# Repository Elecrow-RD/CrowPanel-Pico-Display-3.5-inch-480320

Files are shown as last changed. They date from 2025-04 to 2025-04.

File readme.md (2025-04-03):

### 1, Product picture

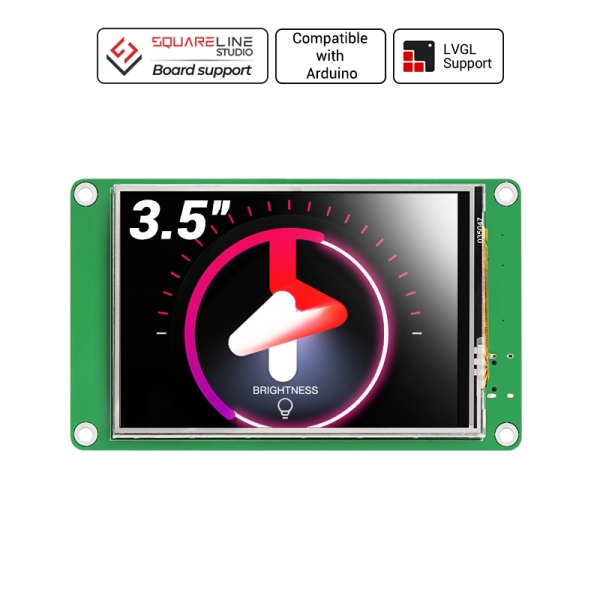
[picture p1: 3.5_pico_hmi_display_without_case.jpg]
3.5_pico_hmi_display_without_case


### 2, Product version number

| | Hardware | Software | Remark |
| ---- | --- | --- | --- |
| 1 | V1.0 | V1.0 | latest |

### 3, product information

- Main Chip: RP2040
- Processor: Dual-core 32-bit ARM Cortex-M0+ @ 133MHz
- Memory: 264kB on-chip SRAM (supports up to 16MB of off-chip flash memory)
- Screen Size: 3.5 inch
- Resolution: 480*320
- Signal Interface: SPI
- Touch Type: Resistive Touch
- Panel Type: TFT LCD
- Power Input: 5V-2A
- Active Area: 53.64*71.52mm(W * H)
- Dimensions: 62.5 * 104.5 * 13.5mm(W * H * D)

### 4, Use the driver module

| Name | dependency library |
| ---- | --- |
| LVGL | lvgl/lvgl@8.3.3 |

### 5,Quick Start

##### Arduino IDE starts

1.Download the library files used by this product to the 'libraries' folder.

C:\Users\Documents\Arduino\libraries\



2.Open the Arduino IDE

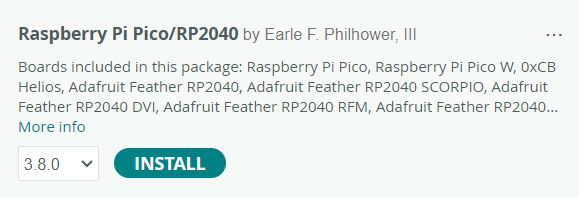
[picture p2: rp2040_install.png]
rp2040_install


3.Open the code configuration environment and burn it

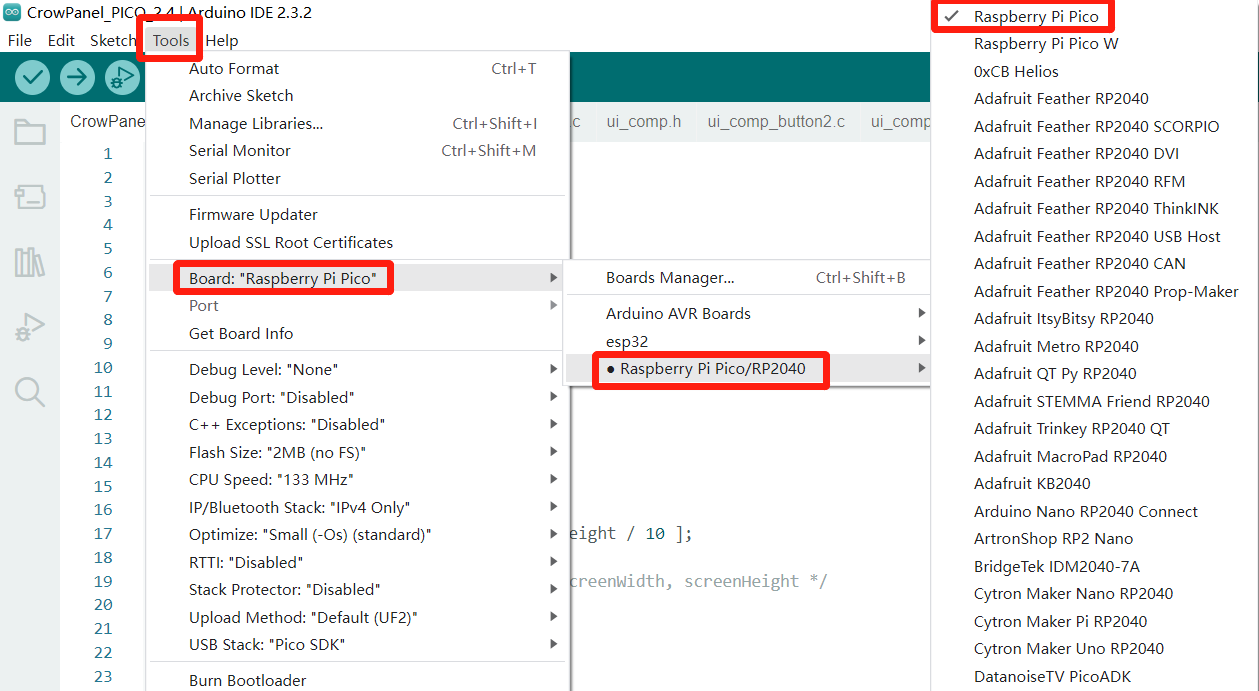
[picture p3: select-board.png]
select-board


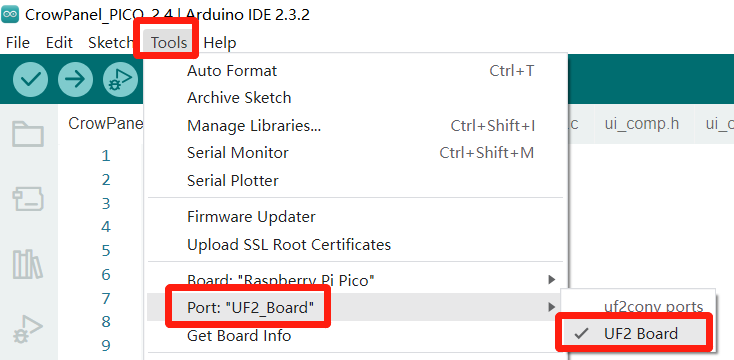
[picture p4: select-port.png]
select-port


### 6,Folder structure.

|--Dimensional Drawing: Contains the dimensional drawing file (.dwg) of the hardware.

|--Datasheet: Includes datasheets for components used in the project, providing detailed specifications, electrical characteristics, and pin configurations.

|--Eagle_SCH&PCB: Contains **Eagle CAD** schematic (`.sch`) and PCB layout (`.brd`) files. These are used for circuit design and PCB manufacturing.

|--example: Provides example code and projects to demonstrate how to use the hardware and libraries. These examples help users get started quickly.

|--factory_firmware: Stores pre-compiled factory firmware that can be directly flashed onto the device. This ensures the device runs the default functionality.

|--factory_sourcecode: Contains the source code for the factory firmware, allowing users to modify and rebuild the firmware as needed.

### 7,Pin definition

#define I2C0_SDA 20

#define I2C0_SCL 21

#SD

const int _MISO = 12;  // AKA SPI RX

const int _MOSI = 11;  // AKA SPI TX

const int _CS = 22;

const int _SCK = 10;

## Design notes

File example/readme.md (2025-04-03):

**Arduino**: This folder contains sample programs for the Arduino platform, which is known for its ease of use and versatility in creating interactive electronic projects.

Link to the corresponding course wiki:https://www.elecrow.com/wiki/CrowPanel_Pico_HMI_3.5-inch_Arduino_Tutorial.html

Video Tutorial Links：https://www.youtube.com/watch?v=5lLdKOjR-Lo&list=PLwh4PlcPx2GdvAtPGuAf1ocWj1UyPWw3W

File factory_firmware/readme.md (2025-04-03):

### pico firmware burning method

##### Press the boot button, plug the pico screen into the computer USB, pop up the disk drive letter



##### Just copy the firmware.uf2 file to the disk drive above

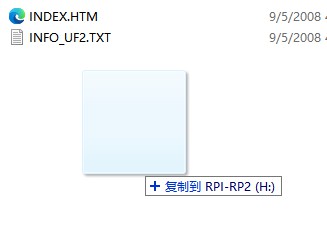
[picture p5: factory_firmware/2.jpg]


##### Demonstration effect

#####

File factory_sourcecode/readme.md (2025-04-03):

- ### Functions Overview

  ### `clearBufferArray()`
  - **Description**: Clears the buffer array by setting all indices to `NULL`.
  - **Parameters**: None
  - **Returns**: None

  ### `my_disp_flush`
  - **Description**: Handles display flushing for LVGL (LittlevGL) graphics library.
  - **Parameters**: 
    - `lv_disp_drv_t *disp_drv`: Pointer to the display driver.
    - `const lv_area_t *area`: Pointer to the area to flush.
    - `lv_color_t *color_p`: Pointer to the color data.
  - **Returns**: None

  ### `my_touchpad_read`
  - **Description**: Reads touchpad input and updates LVGL input device data.
  - **Parameters**: 
    - `lv_indev_drv_t * indev_driver`: Pointer to the input device driver.
    - `lv_indev_data_t * data`: Pointer to the input device data.
  - **Returns**: None

  #### `callback1`
  - **Description**: Callback function for updating UI elements based on certain conditions.
  - **Parameters**: None
  - **Returns**: None

  #### `setup`
  - **Description**: Initializes the system, including serial communication, display, and LVGL.
  - **Parameters**: None
  - **Returns**: None

  #### `loop`
  - **Description**: Main loop of the program handling various tasks and user inputs.
  - **Parameters**: None
  - **Returns**: None

  #### `Ce_shi`
  - **Description**: Clears the screen and handles different test cases based on serial input.
  - **Parameters**: None
  - **Returns**: None

  ### `SD_test`
  - **Description**: Tests and initializes the SD card.
  - **Parameters**: None
  - **Returns**: None

  ### `printDirectory`
  - **Description**: Prints the contents of a directory to the serial output.
  - **Parameters**: 
    - `File dir`: Directory to print.
    - `int numTabs`: Number of tabs for formatting.
  - **Returns**: None

  #### `label_xy`
  - **Description**: Creates and configures touch labels on the screen.
  - **Parameters**: None
  - **Returns**: None

  #### `lv_example_bar`
  - **Description**: Creates and configures a bar widget for the UI.
  - **Parameters**: None
  - **Returns**: None

  #### `Home_Page_Create`
  - **Description**: Sets up the home page with a black background.
  - **Parameters**: None
  - **Returns**: None

  #### `touch_calibrate`
  - **Description**: Calibrates the touch screen and sends calibration data to the serial port.
  - **Parameters**: None
  - **Returns**: None

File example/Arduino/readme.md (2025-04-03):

# Library Descriptions

## Adafruit_BusIO
Adafruit_BusIO is a library that provides a common interface for communicating with I2C, SPI, and other bus protocols on microcontrollers like the Raspberry Pi Pico.

## Adafruit_GFX_Library
The Adafruit GFX Library is a graphics library that simplifies drawing shapes, text, and images on displays connected to microcontrollers.

## Adafruit_seesaw_Library
The Adafruit seesaw Library allows you to communicate with Adafruit's seesaw devices, which can add additional functionality such as capacitive touch sensing or analog-to-digital conversion to your projects.

## Adafruit_ST7735_and_ST7789_Library
This library supports the ST7735 and ST7789 display controllers, commonly used in small TFT displays.

## DHT20
The DHT20 library is designed for interfacing with the DHT20 temperature and humidity sensor.

## GFX_Library_for_Arduino
This is likely another graphics library specifically tailored for Arduino-based projects.

## GuSlice
GuSlice might be a library for handling graphical user interface elements, particularly slices or segments of a display.

## lvg1
lvg1 could refer to a version or variant of the LittlevGL (LVGL) library, which is a popular open-source GUI library.

## TFT_eSPI
TFT_eSPI is a library for driving TFT displays using the SPI protocol, often used with ESP8266 and ESP32 microcontrollers.

## Ticker
Ticker is typically a library for creating software timers or scheduling tasks at regular intervals.

## UI
UI generally refers to a set of functions or classes related to the user interface, possibly custom code or part of a larger framework.

## Wire
Wire is a library for I2C communication, allowing microcontrollers to talk to each other and to various sensors and modules over the I2C bus.

## XPT2046_Touchscreen
This library interfaces with the XPT2046 touchscreen controller, enabling touch input on compatible displays.

## lv_conf.h
lv_conf.h is a configuration file for the LVGL library where you can define various settings and options to tailor the library's behavior to your specific needs.

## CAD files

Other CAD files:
Dimension_figure/3.5_inch_dimension_figure/3.5inch.dwg

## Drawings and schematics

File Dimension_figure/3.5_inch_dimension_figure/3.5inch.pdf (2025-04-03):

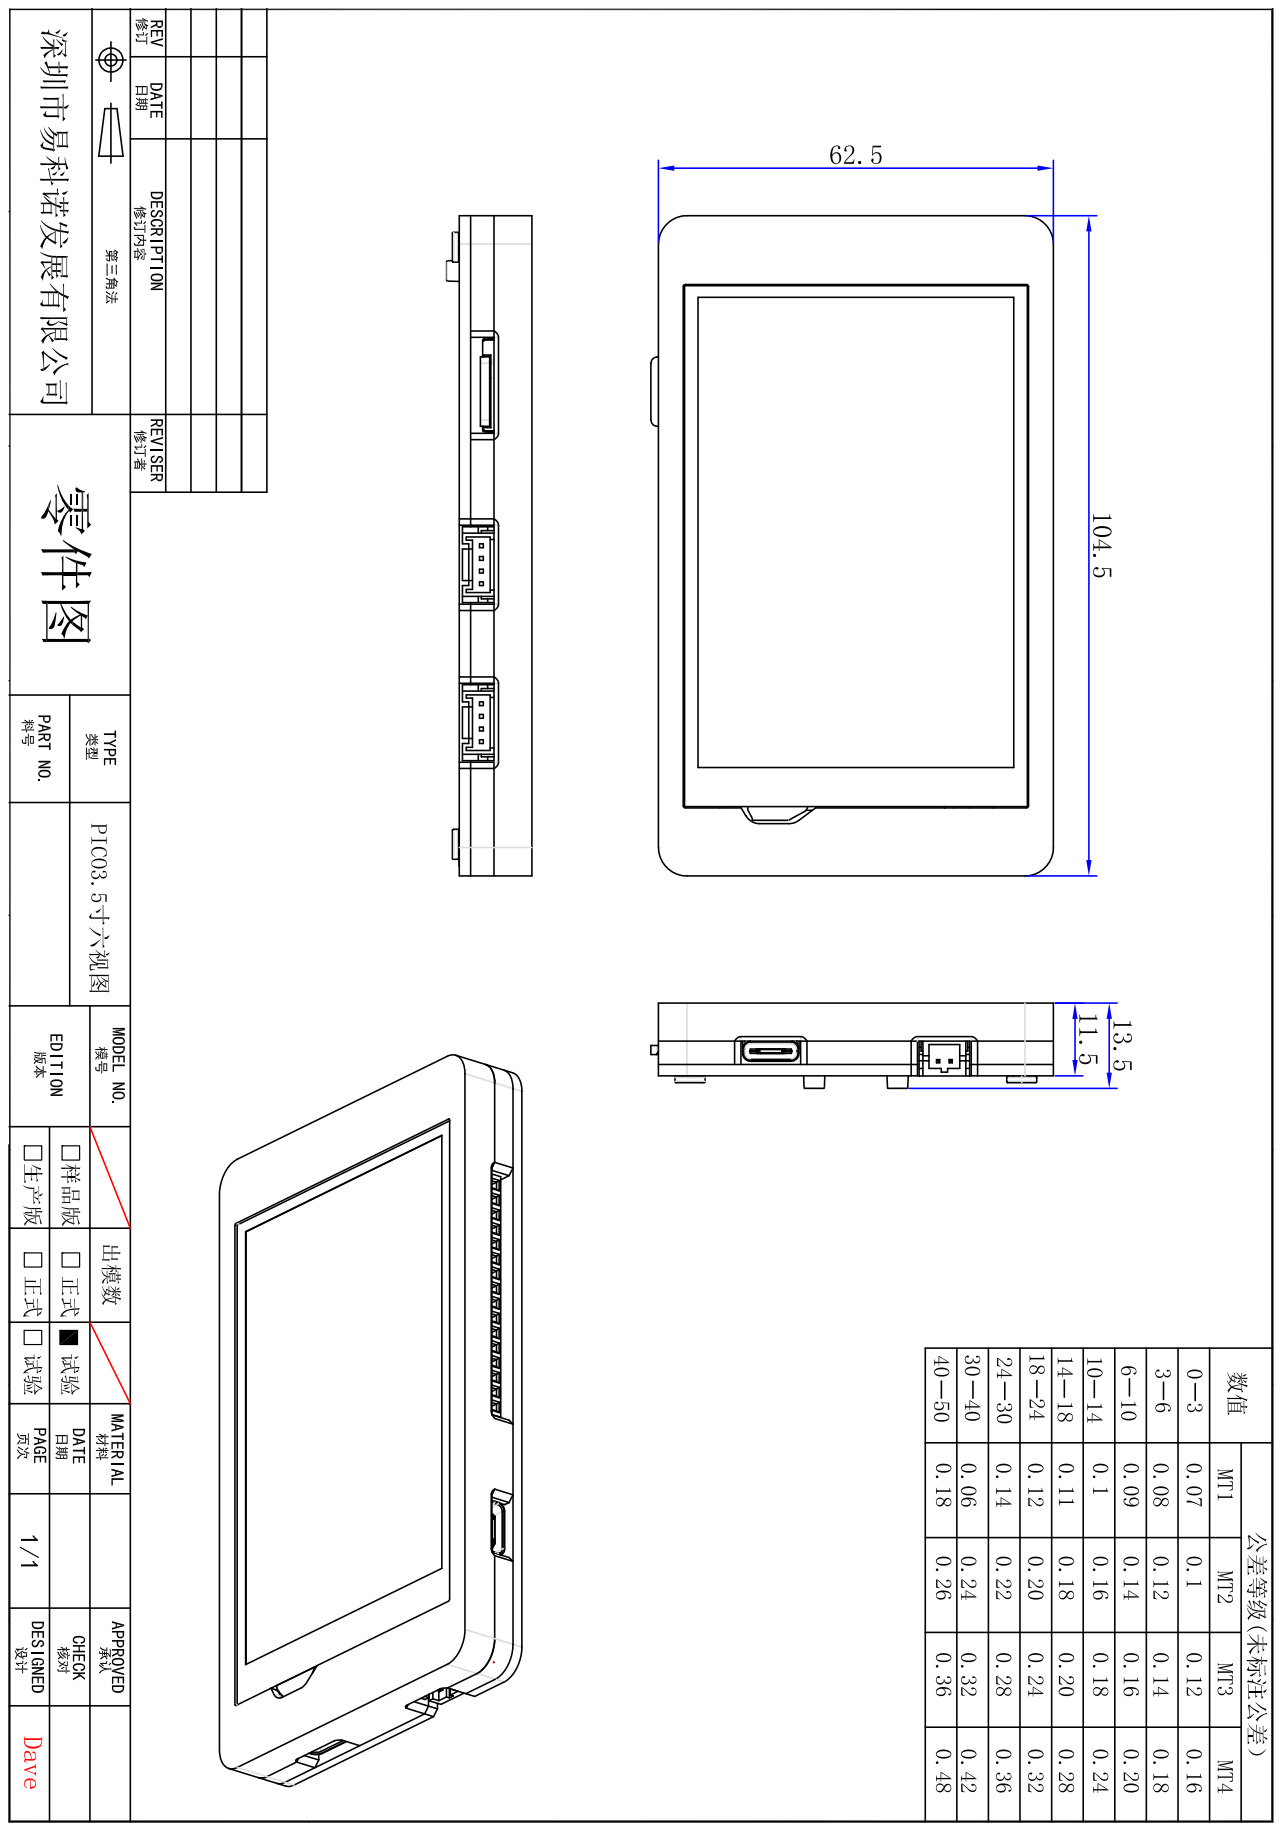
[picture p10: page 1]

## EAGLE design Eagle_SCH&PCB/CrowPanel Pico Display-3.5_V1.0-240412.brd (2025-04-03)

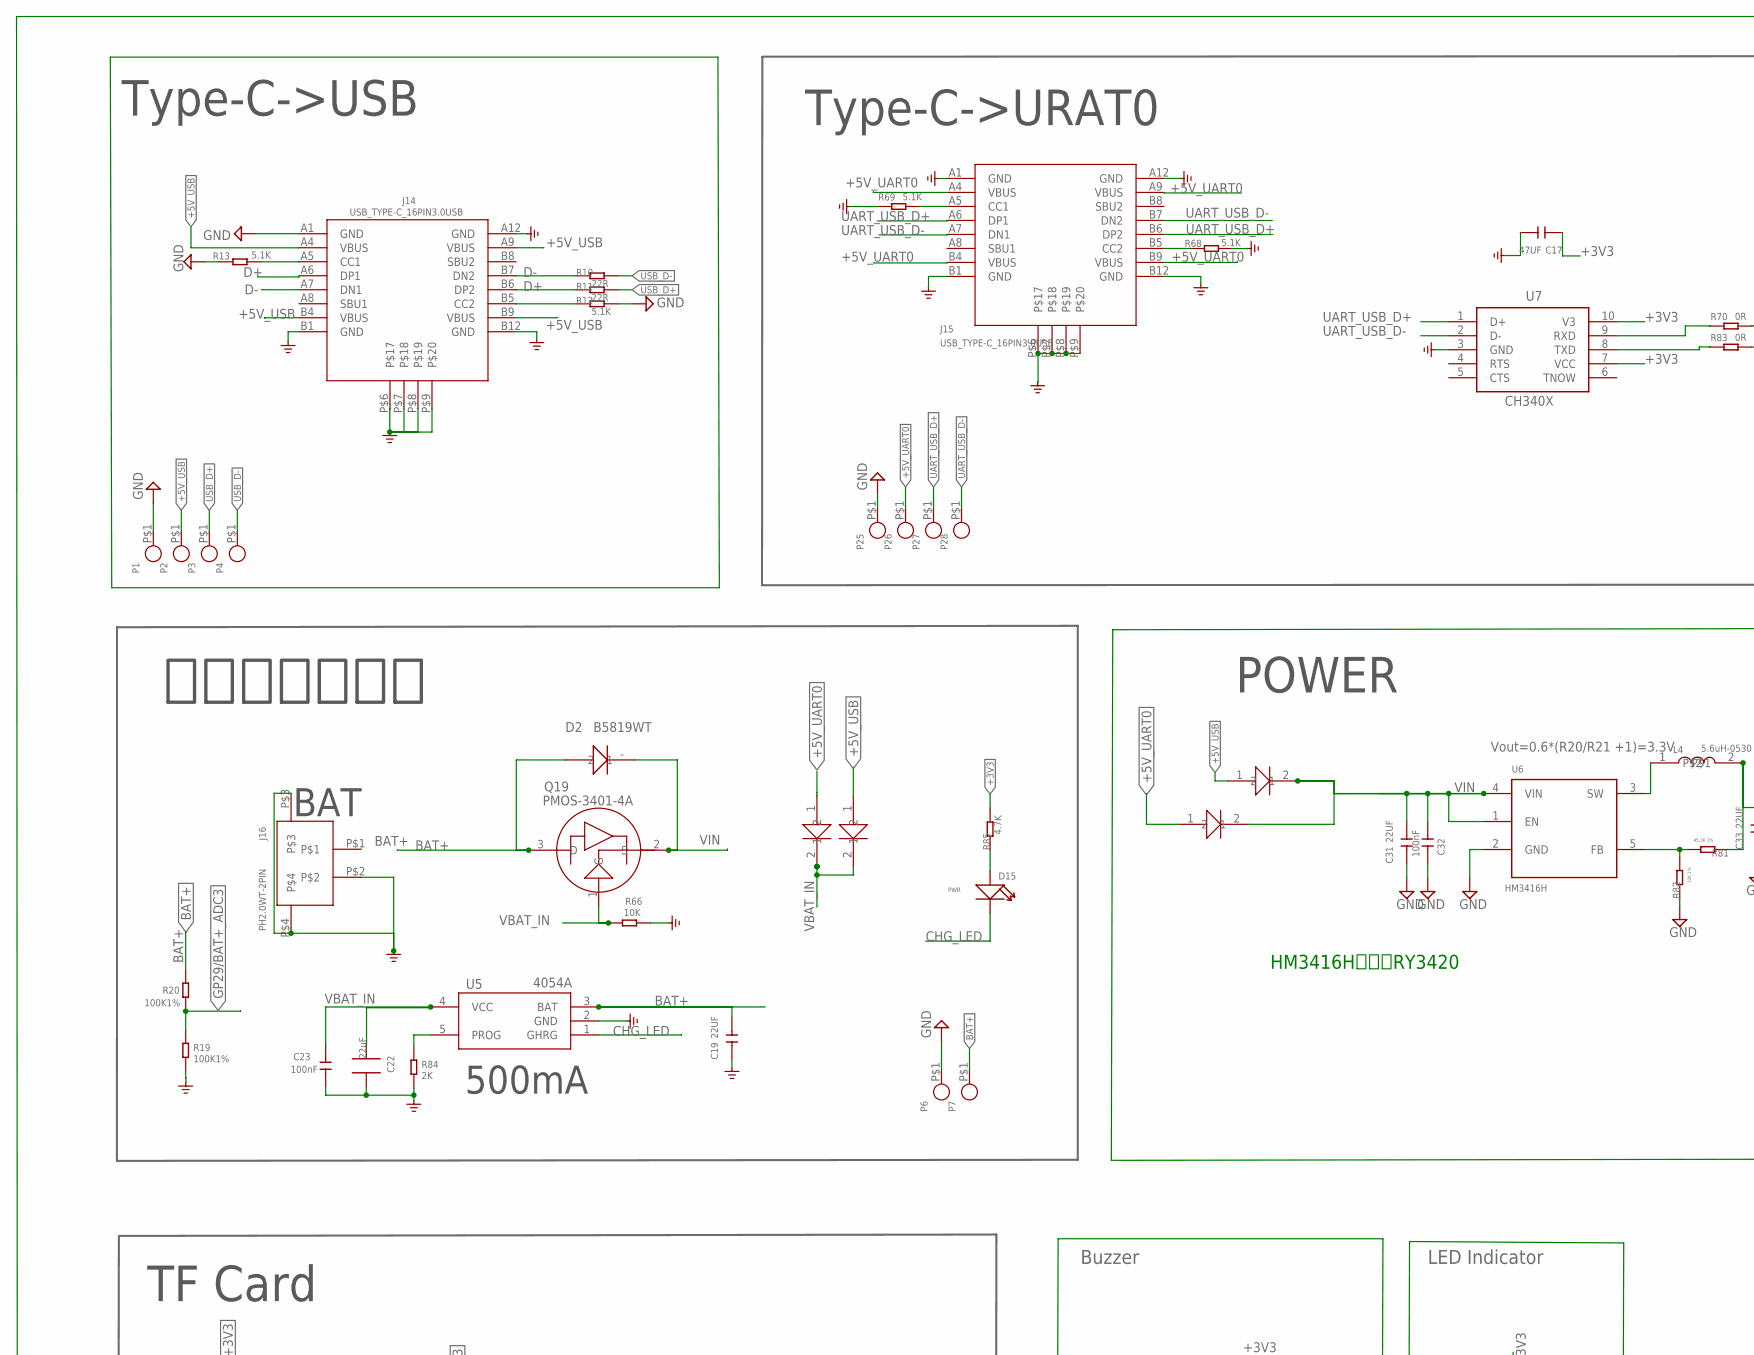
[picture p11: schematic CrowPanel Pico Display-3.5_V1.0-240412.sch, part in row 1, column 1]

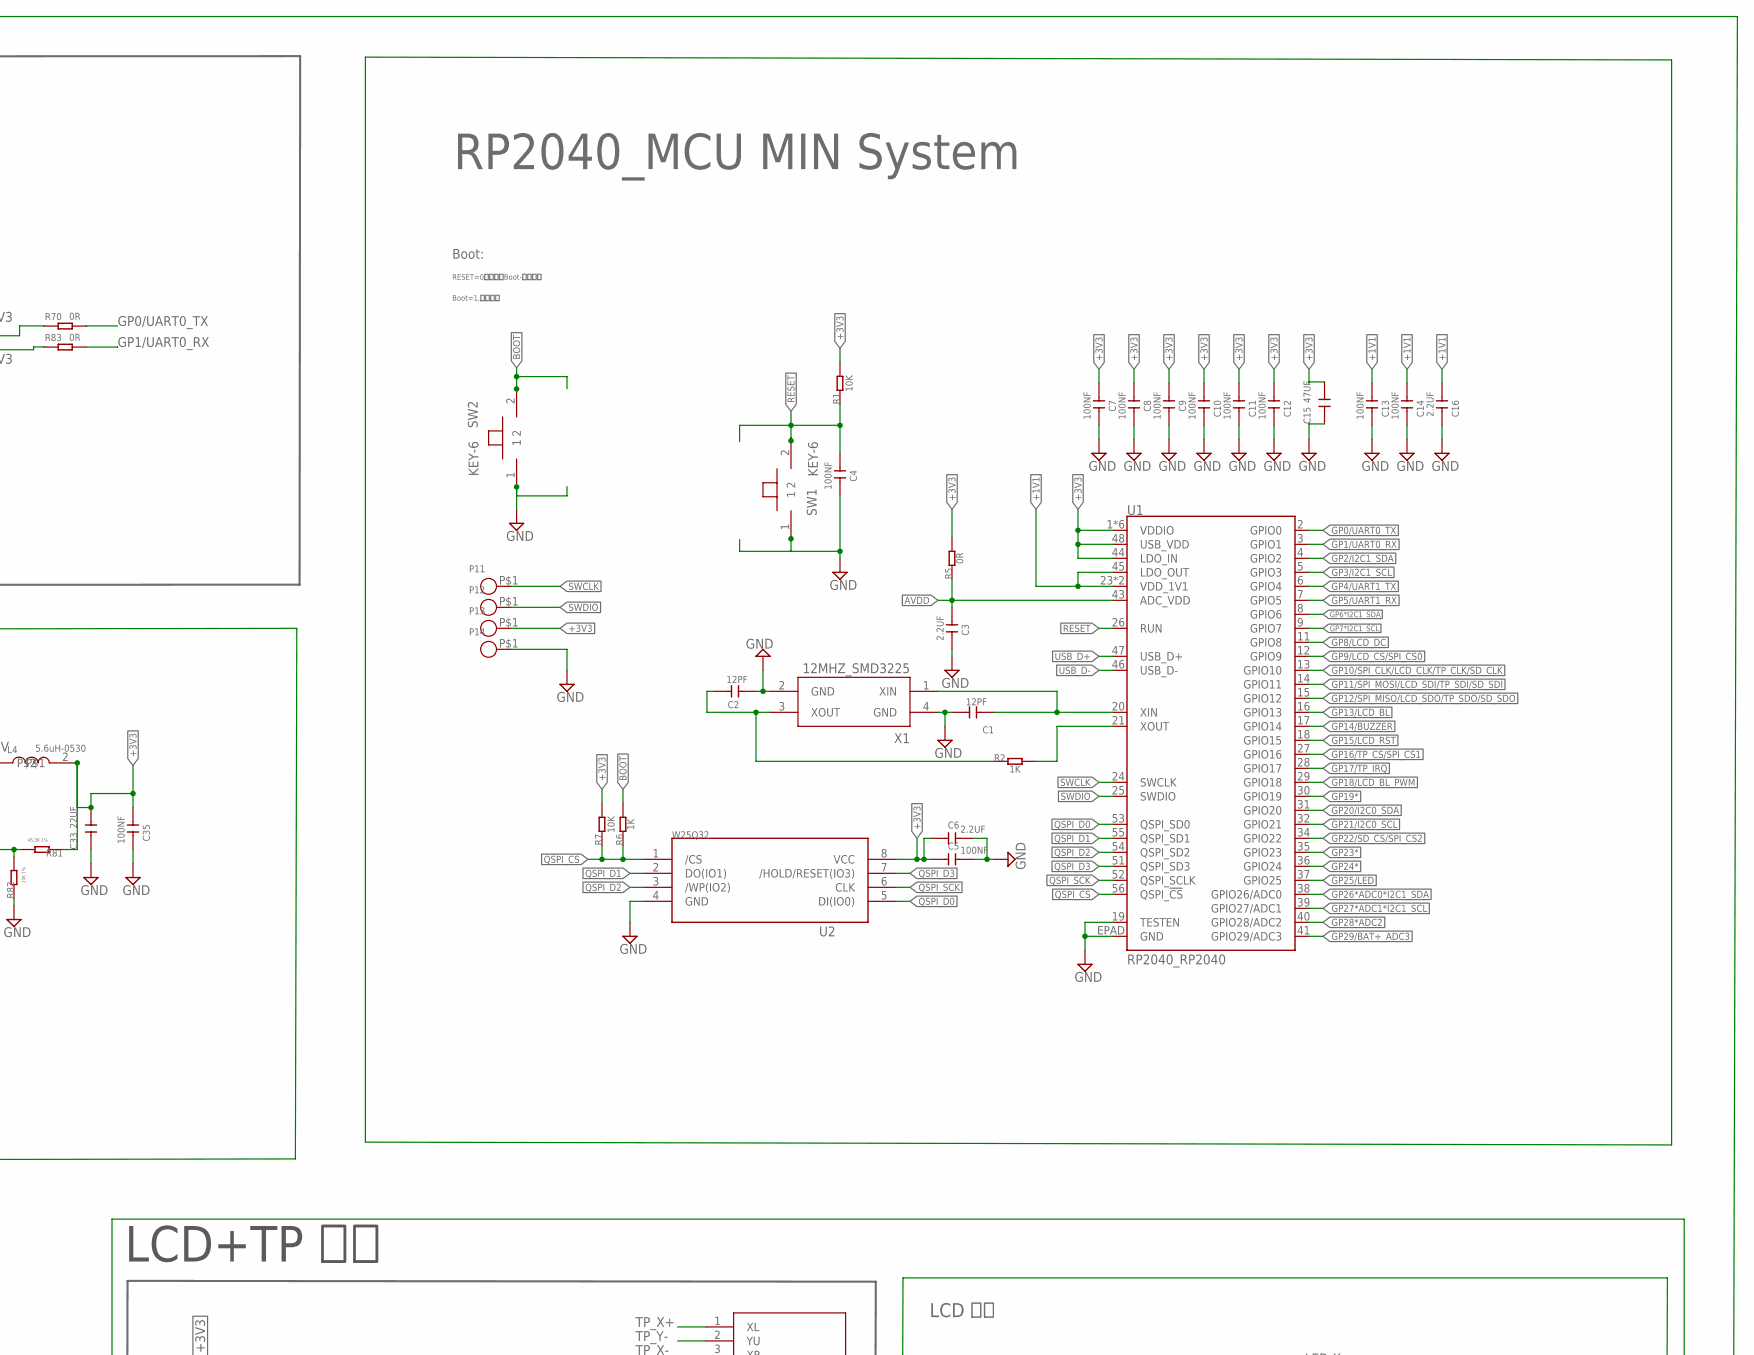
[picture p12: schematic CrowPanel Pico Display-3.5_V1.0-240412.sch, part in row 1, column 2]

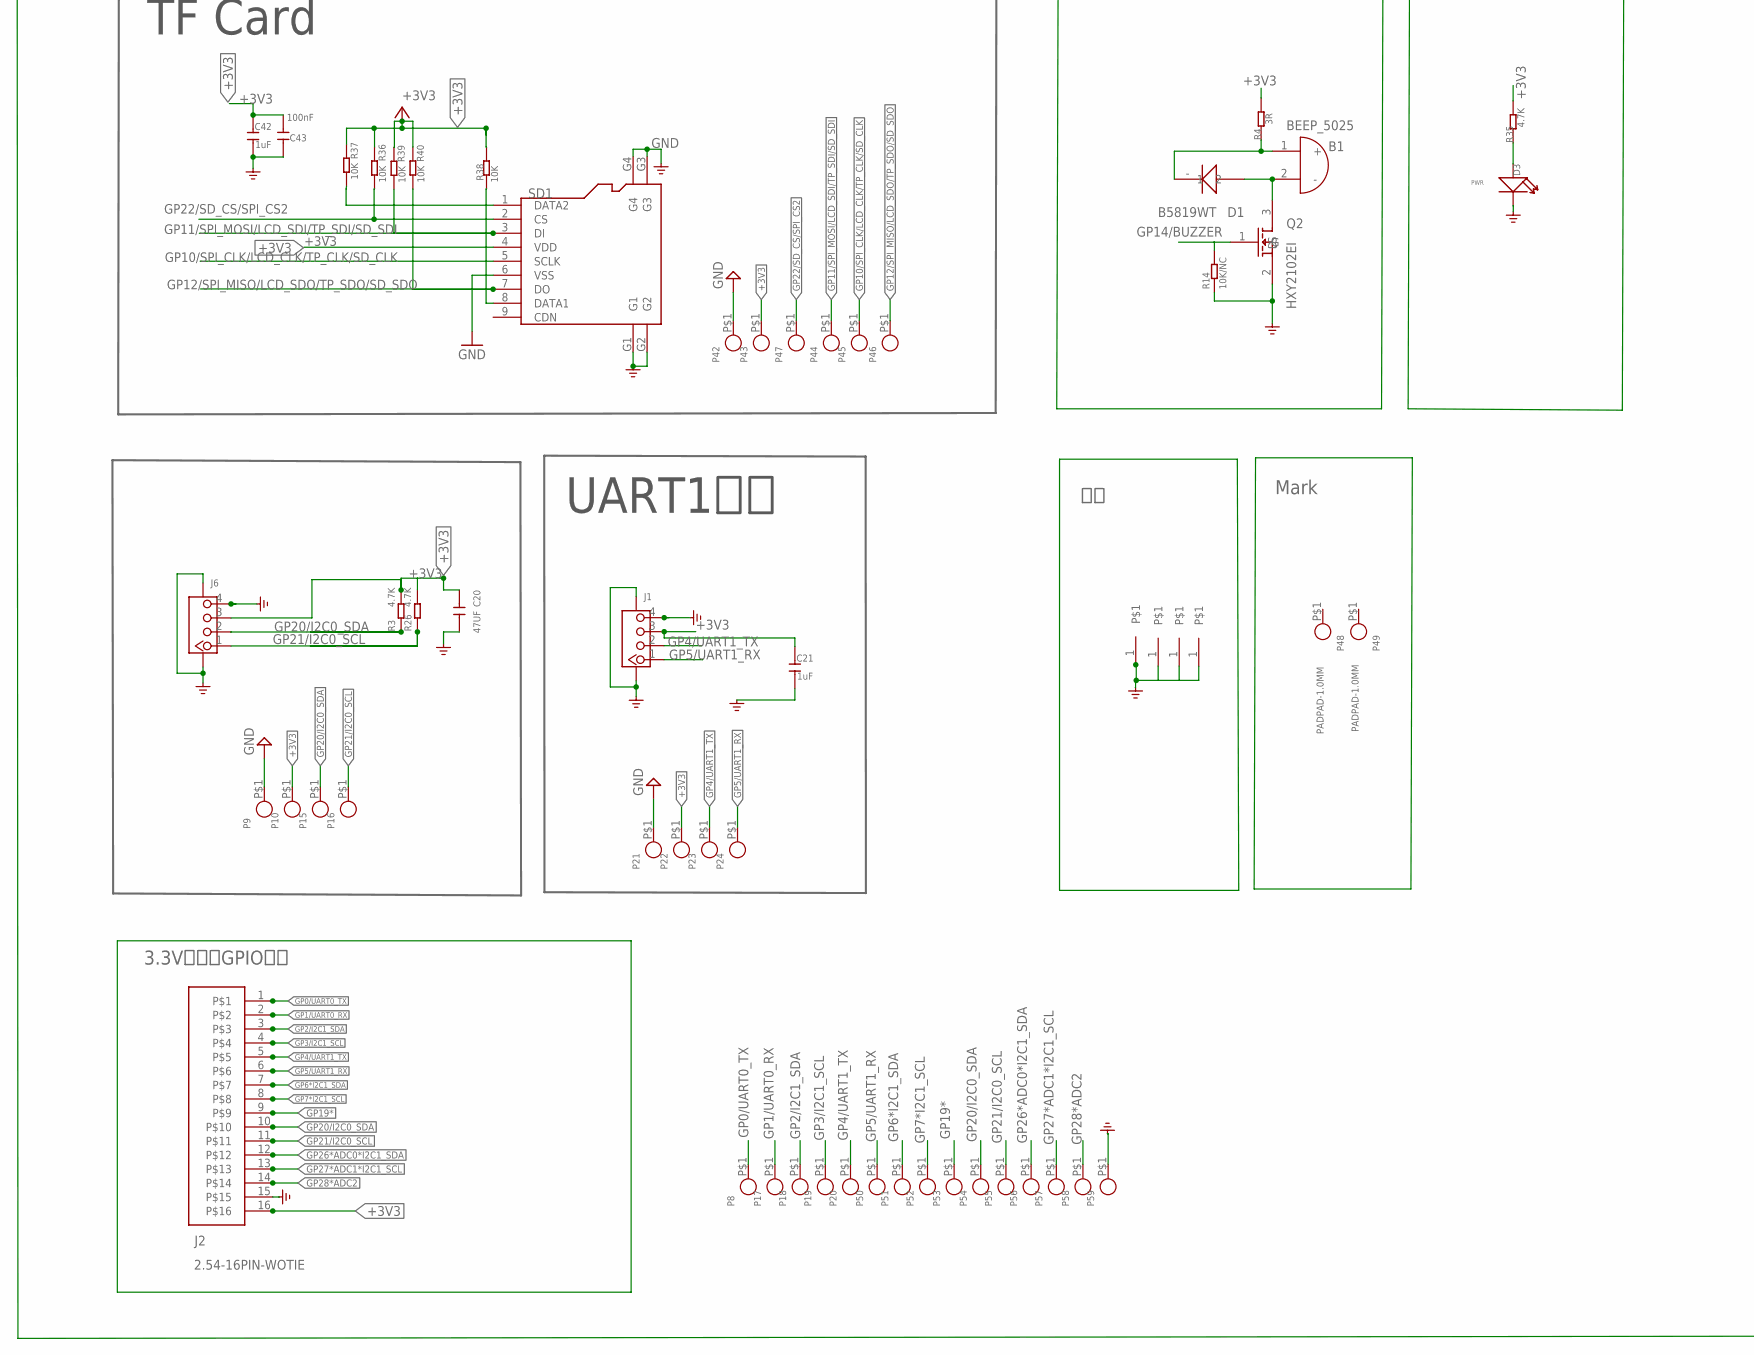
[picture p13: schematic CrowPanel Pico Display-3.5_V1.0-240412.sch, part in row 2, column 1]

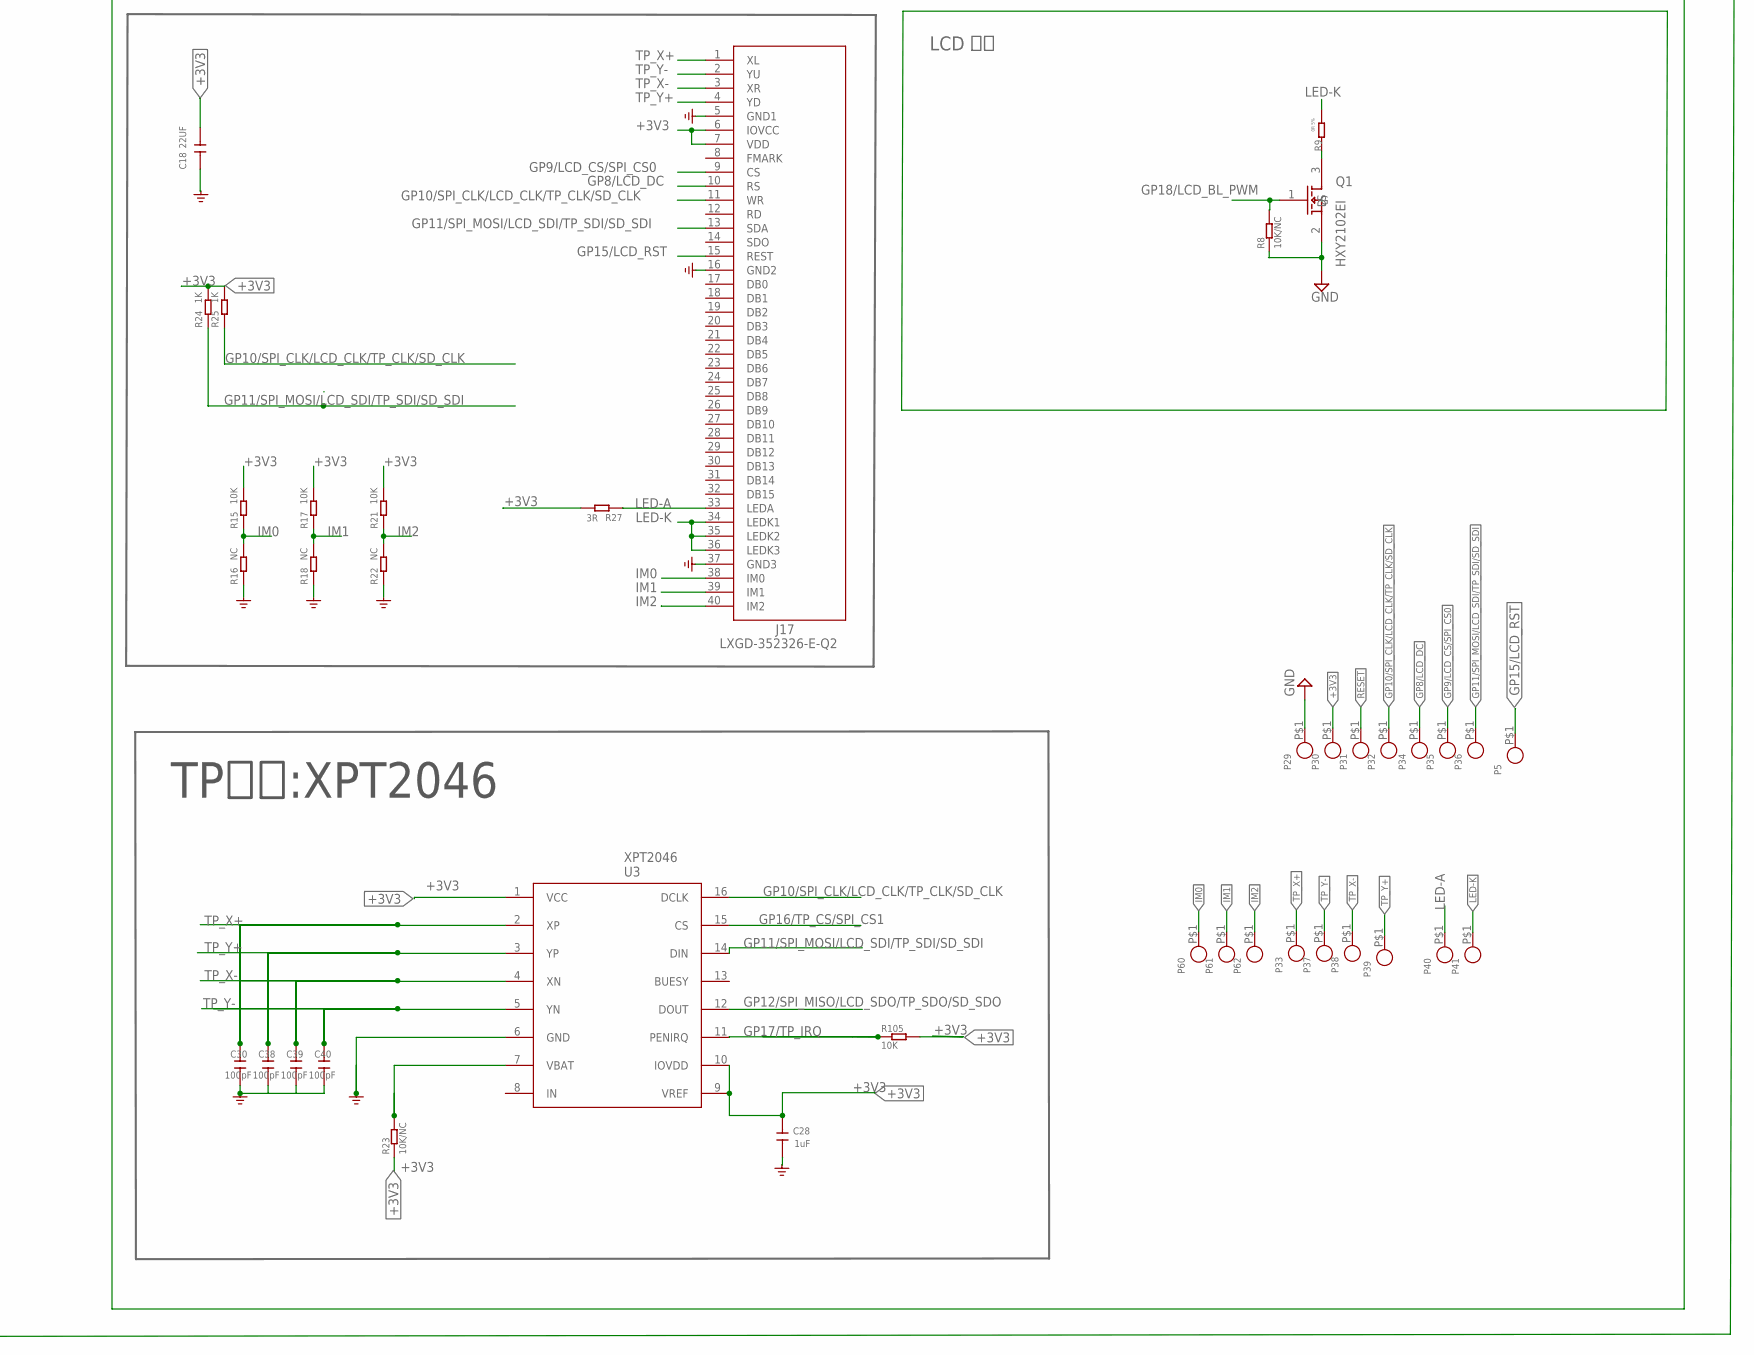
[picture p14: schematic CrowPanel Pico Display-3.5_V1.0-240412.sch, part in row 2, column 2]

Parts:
B1: BEEP_5025
C1, C2: 12PF; A_XBJ_0603
C3, C6, C16: 2.2UF; A_XBJ_0603
C4, C5, C7, C8, C9, C10, C11, C12, C13, C14, C35: 100NF; A_XBJ_0603
C15, C17, C20: 47UF; A_XBJ_0805
C18, C19, C31, C33: 22UF; A_XBJ_0805
C21, C28, C42: 1uF; DISCRETE_C0603
C22: 22uF; 0805_S
C23, C43: 100nF; C0603
C30, C38, C39, C40: 100pF; 0603
C32: 100nF; A_XBJ_0603
D1, D2: B5819WT; SOD-523
D3, D15: DISCRETE_007-LED0603; DISCRETE_D0603
D4, D5, D6, D8: SOD-323
J1, J6: CONNECTOR_TWIG-4P-2.0-SMD-FEMALE-REINFORCE90D; CONNECTOR_4P-SMD-2.0-90D
J2: 2.54-16PIN-WOTIE; 2.54-16P-WOTIE
J14, J15: USB_TYPE-C_16PIN3.0USB; KEVIN_3.0TYPEC-SMD
J16: PH2.0WT-2PIN
J17: LXGD-352326-E-Q2; 40PIN-0.5MM
L4: 5.6uH-0530; CD54_CD54
P1, P2, P3, P4, P5, P6, P7, P8, P9, P10, P11, P12, P13, P14, P15, P16, P17, P18, P19, P20, P21, P22, P23, P24, P25, P26, P27, P28, P29, P30, P31, P32, P33, P34, P35, P36, P37, P38, P39, P40, P41, P42, P43, P44, P45, P46, P47, P50, P51, P52, P53, P54, P55, P56, P57, P58, P59, P60, P61, P62: CROWPI_POW_PADPAD-1.0MM; CROWPI_POW_PAD-1.0MM
P48, P49: PADPAD-1.0MM; PAD-1.0MM
Q1, Q2: HXY2102EI; SOT-323_W
Q19: PMOS-3401-4A; SOT-23
R1, R7, R15, R17, R21, R36, R37, R38, R39, R40, R66, R105: 10K; DISCRETE_R0603
R2, R6, R24, R25: 1K; DISCRETE_R0603
R3, R26, R35, R85: 4.7K; DISCRETE_R0603
R4, R27: 3R; DISCRETE_R0603
R5, R70, R83: 0R; DISCRETE_R0603
R8, R14, R23: 10K/NC; DISCRETE_R0603
R9: 0R 5%; DISCRETE_R0603
R10, R11: 22R; DISCRETE_R0603
R12, R13, R68, R69: 5.1K; DISCRETE_R0603
R16, R18, R22: NC; DISCRETE_R0603
R19, R20: 100K1%; DISCRETE_R0603
R81: 45.3K 1%; DISCRETE_R0603
R82: 10K 1%; DISCRETE_R0603
R84: 2K; DISCRETE_R0603
SD1: HOLDER-MICROSD-9P; 9P-SMD-W/-RING
SW1, SW2: KEY-6
T1, T2, T3, T4: 3M-5
U1: RP2040_RP2040; RP2040_QFN-56
U2: SELF_W25Q128JV; SELF_SOIC-8-208MIL
U3: XPT2046; XP2046-SSOP16
U5: 4054A; SOP23-5
U6: HM3416H; CROWBOT_-V1.0-20220525_A_XBJ_SOT23-5
U7: CH340X; MSOP-10_W
X1: 12MHZ_SMD3225; A_XBJ_SMD3225

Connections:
+1V1: C13.1, C14.1, C16.1, U1.23 (VDD_1V1), U1.45 (LDO_OUT), U1.50 (VDD_1V1)
+3V3: C5.1, C6.1, C7.1, C8.1, C9.1, C10.1, C11.1, C12.1, C15.2, C17.1, C18.2, C20.1, C21.2, C28.2, C33.2, C35.1, C42.2, C43.1, J1.3, J2.16, J6.3, J17.6 (IOVCC), J17.7 (VDD), L4.2, P10.P$1, P13.P$1, P22.P$1, P30.P$1, P43.P$1, R1.2, R3.2, R4.2, R5.2, R7.2, R15.2, R17.2, R21.2, R23.1, R24.2, R25.2, R26.2, R27.2, R35.2, R36.1, R37.1, R38.1, R39.1, R40.1, R81.1, R85.2, R105.2, SD1.4 (VDD), U1.1 (VDDIO), U1.10 (VDDIO), U1.22 (VDDIO), U1.33 (VDDIO), U1.42 (VDDIO), U1.44 (LDO_IN), U1.48 (USB_VDD), U1.49 (VDDIO), U2.8 (VCC), U3.1 (VCC), U3.9 (VREF), U3.10 (IOVDD), U7.7 (VCC), U7.10 (V3)
+5V_UART0: D4.1, D8.1, J15.A4 (VBUS), J15.A9 (VBUS), J15.B4 (VBUS), J15.B9 (VBUS), P26.P$1
+5V_USB: D5.1, D6.1, J14.A4 (VBUS), J14.A9 (VBUS), J14.B4 (VBUS), J14.B9 (VBUS), P2.P$1
AVDD: C3.1, R5.1, U1.43 (ADC_VDD)
BAT+: C19.2, D2.+ (1), J16.P$1, P7.P$1, Q19.3 (D), R20.1, U5.3 (BAT)
BOOT: R6.2, SW2.2
CHG_LED: D15.-, U5.1 (GHRG)
D+: J14.A6 (DP1), J14.B6 (DP2), R11.1
D-: J14.A7 (DN1), J14.B7 (DN2), R10.1
GND: C1.2, C2.1, C3.2, C4.2, C5.2, C6.2, C7.2, C8.2, C9.2, C10.2, C11.2, C12.2, C13.2, C14.2, C15.1, C16.2, C17.2, C18.1, C19.1, C20.2, C21.1, C22.1, C23.2, C28.1, C30.1, C31.1, C32.2, C33.1, C35.2, C38.1, C39.1, C40.1, C42.1, C43.2, D3.-, J1.4, J1.SS1, J1.SS2, J2.15, J6.4, J6.SS1, J6.SS2, J14.A1 (GND), J14.A12 (GND), J14.B1 (GND), J14.B12 (GND), J14.P$6, J14.P$7, J14.P$8, J14.P$9, J15.A1 (GND), J15.A12 (GND), J15.B1 (GND), J15.B12 (GND), J15.P$6, J15.P$7, J15.P$8, J15.P$9, J16.P$2, J16.P$3, J16.P$4, J17.5 (GND1), J17.16 (GND2), J17.37 (GND3), P1.P$1, P6.P$1, P9.P$1, P14.P$1, P21.P$1, P25.P$1, P29.P$1, P42.P$1, P59.P$1, Q1.2 (S), Q2.2 (S), R8.1, R12.2, R13.1, R14.1, R16.1, R18.1, R19.2, R22.1, R66.1, R68.2, R69.1, R82.1, R84.2, SD1.6 (VSS), SD1.G1, SD1.G2, SD1.G3, SD1.G4, SW1.1, SW2.1, T1.1, T2.1, T3.1, T4.1, U1.19 (TESTEN), U1.EPAD (GND), U2.4 (GND), U3.6 (GND), U5.2 (GND), U6.2 (GND), U7.3 (GND), X1.2 (GND), X1.4 (GND)
GP0/UART0_TX: J2.1, P8.P$1, R70.2, U1.2 (GPIO0)
GP1/UART0_RX: J2.2, P17.P$1, R83.2, U1.3 (GPIO1)
GP2/I2C1_SDA: J2.3, P18.P$1, U1.4 (GPIO2)
GP3/I2C1_SCL: J2.4, P19.P$1, U1.5 (GPIO3)
GP4/UART1_TX: J1.2, J2.5, P20.P$1, P23.P$1, U1.6 (GPIO4)
GP5/UART1_RX: J1.1, J2.6, P24.P$1, P50.P$1, U1.7 (GPIO5)
GP6*I2C1_SDA: J2.7, P51.P$1, U1.8 (GPIO6)
GP7*I2C1_SCL: J2.8, P52.P$1, U1.9 (GPIO7)
GP8/LCD_DC: J17.10 (RS), P34.P$1, U1.11 (GPIO8)
GP9/LCD_CS/SPI_CS0: J17.9 (CS), P35.P$1, U1.12 (GPIO9)
GP10/SPI_CLK/LCD_CLK/TP_CLK/SD_CLK: J17.11 (WR), P32.P$1, P45.P$1, R25.1, SD1.5 (SCLK), U1.13 (GPIO10), U3.16 (DCLK)
GP11/SPI_MOSI/LCD_SDI/TP_SDI/SD_SDI: J17.13 (SDA), P36.P$1, P44.P$1, R24.1, R39.2, SD1.3 (DI), U1.14 (GPIO11), U3.14 (DIN)
GP12/SPI_MISO/LCD_SDO/TP_SDO/SD_SDO: P46.P$1, R40.2, SD1.7 (DO), U1.15 (GPIO12), U3.12 (DOUT)
GP13/LCD_BL: U1.16 (GPIO13)
GP14/BUZZER: Q2.1 (G), R14.2, U1.17 (GPIO14)
GP15/LCD_RST: J17.15 (REST), P5.P$1, U1.18 (GPIO15)
GP16/TP_CS/SPI_CS1: U1.27 (GPIO16), U3.15 (CS)
GP17/TP_IRQ: R105.1, U1.28 (GPIO17), U3.11 (PENIRQ)
GP18/LCD_BL_PWM: Q1.1 (G), R8.2, U1.29 (GPIO18)
GP19*: J2.9, P53.P$1, U1.30 (GPIO19)
GP20/I2C0_SDA: J2.10, J6.2, P15.P$1, P54.P$1, R3.1, U1.31 (GPIO20)
GP21/I2C0_SCL: J2.11, J6.1, P16.P$1, P55.P$1, R26.1, U1.32 (GPIO21)
GP22/SD_CS/SPI_CS2: P47.P$1, R36.2, SD1.2 (CS), U1.34 (GPIO22)
GP23*: U1.35 (GPIO23)
GP24*: U1.36 (GPIO24)
GP25/LED: U1.37 (GPIO25)
GP26*ADC0*I2C1_SDA: J2.12, P56.P$1, U1.38 (GPIO26/ADC0)
GP27*ADC1*I2C1_SCL: J2.13, P57.P$1, U1.39 (GPIO27/ADC1)
GP28*ADC2: J2.14, P58.P$1, U1.40 (GPIO28/ADC2)
GP29/BAT+_ADC3: R19.1, R20.2, U1.41 (GPIO29/ADC3)
IM0: J17.38 (IM0), P60.P$1, R15.1, R16.2
IM1: J17.39 (IM1), P61.P$1, R17.1, R18.2
IM2: J17.40 (IM2), P62.P$1, R21.1, R22.2
LED-A: J17.33 (LEDA), P40.P$1, R27.1
LED-K: J17.34 (LEDK1), J17.35 (LEDK2), J17.36 (LEDK3), P41.P$1, R9.2
unnamed: C2.2, R2.1, X1.3 (XOUT)
unnamed: R2.2, U1.21 (XOUT)
unnamed: C1.1, U1.20 (XIN), X1.1 (XIN)
unnamed: B1.1 (+), D1.- (2), R4.1
unnamed: J15.B5 (CC2), R68.1
unnamed: B1.2 (-), D1.+ (1), Q2.3 (D)
unnamed: Q1.3 (D), R9.1
unnamed: R84.1, U5.5 (PROG)
unnamed: L4.1, U6.3 (SW)
unnamed: J14.A5 (CC1), R13.2
unnamed: D15.+, R85.1
unnamed: J15.A5 (CC1), R69.2
unnamed: J14.B5 (CC2), R12.1
unnamed: R23.2, U3.7 (VBAT)
unnamed: R37.2, SD1.1 (DATA2)
unnamed: R38.2, SD1.8 (DATA1)
unnamed: R70.1, U7.9 (RXD)
unnamed: R83.1, U7.8 (TXD)
unnamed: D3.+, R35.1
unnamed: R81.2, R82.2, U6.5 (FB)
QSPI_CS: R6.1, R7.1, U1.56 (QSPI_!CS!), U2.1 (/CS)
QSPI_D0: U1.53 (QSPI_SD0), U2.5 (DI(IO0))
QSPI_D1: U1.55 (QSPI_SD1), U2.2 (DO(IO1))
QSPI_D2: U1.54 (QSPI_SD2), U2.3 (/WP(IO2))
QSPI_D3: U1.51 (QSPI_SD3), U2.7 (/HOLD/RESET(IO3))
QSPI_SCK: U1.52 (QSPI_SCLK), U2.6 (CLK)
RESET: C4.1, P31.P$1, R1.1, SW1.2, U1.26 (RUN)
SWCLK: P11.P$1, U1.24 (SWCLK)
SWDIO: P12.P$1, U1.25 (SWDIO)
TP_X+: C30.2, J17.1 (XL), P33.P$1, U3.2 (XP)
TP_X-: C39.2, J17.3 (XR), P38.P$1, U3.4 (XN)
TP_Y+: C38.2, J17.4 (YD), P39.P$1, U3.3 (YP)
TP_Y-: C40.2, J17.2 (YU), P37.P$1, U3.5 (YN)
UART_USB_D+: J15.A6 (DP1), J15.B6 (DP2), P27.P$1, U7.1 (D+)
UART_USB_D-: J15.A7 (DN1), J15.B7 (DN2), P28.P$1, U7.2 (D-)
USB_D+: P3.P$1, R11.2, U1.47 (USB_D+)
USB_D-: P4.P$1, R10.2, U1.46 (USB_D-)
VBAT_IN: C22.2, C23.1, D4.2, D5.2, Q19.1 (G), R66.2, U5.4 (VCC)
VIN: C31.2, C32.1, D2.- (2), D6.2, D8.2, Q19.2 (S), U6.1 (EN), U6.4 (VIN)

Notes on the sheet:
RP2040_MCU MIN System
Buzzer
LED Indicator
3.3V电源，GPIO排针
Vout=0.6*(R20/R21 +1)=3.3V
Boot:
RESET=0时，按下Boot-下载模式
Boot=1,正常运行
PWR
W25Q32
Type-C->URAT0
电池及充电电路
500mA
BAT
Type-C->USB
LCD+TP 接口
TP驱动:XPT2046
TF Card
UART1接口
LCD 背光
POWER
Mark
HM3416H更换为RY3420

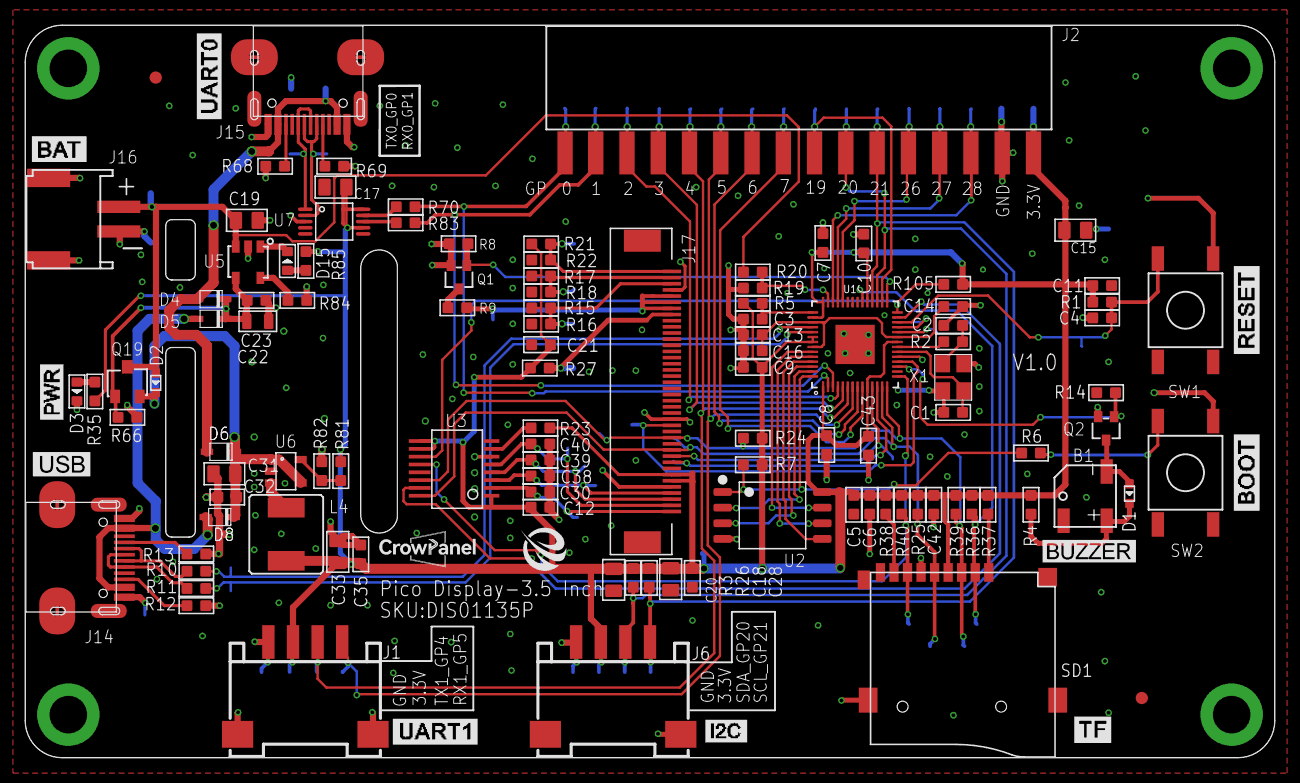
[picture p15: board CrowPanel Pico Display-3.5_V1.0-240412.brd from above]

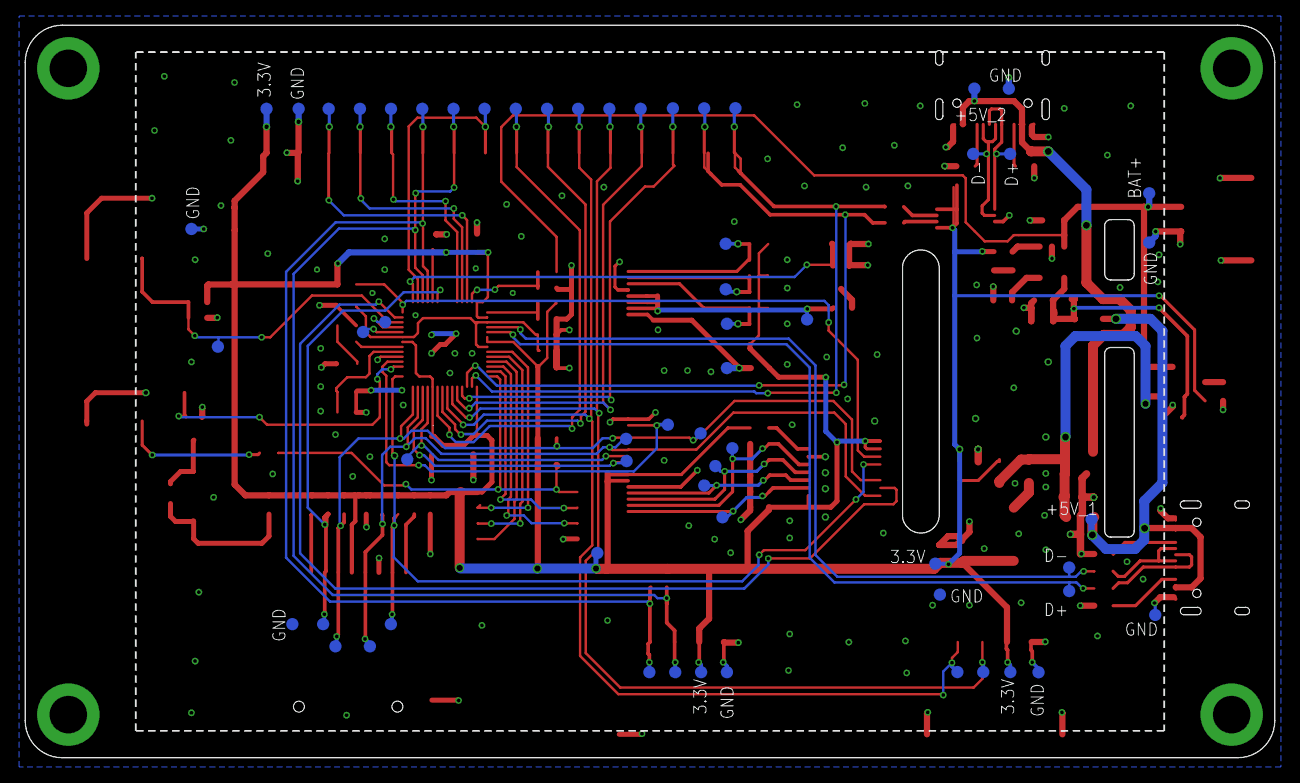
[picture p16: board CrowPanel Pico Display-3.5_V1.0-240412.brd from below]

Board: 2 copper layers, 101.5 x 59.5 mm, 173 parts (60 on the bottom side), 81 nets.

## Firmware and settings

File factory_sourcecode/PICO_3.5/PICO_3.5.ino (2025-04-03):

/*Using LVGL with Arduino requires some extra steps:
  Be sure to read the docs here: https://docs.lvgl.io/master/get-started/platforms/arduino.html  */
#include <Arduino.h>
#include <lvgl.h>
#include <TFT_eSPI.h>
#include <../lvgl/src/demos/lv_demos.h>
#include "ui.h"
#include <Ticker.h> 
#include <hardware/watchdog.h>
static int first_flag = 0;
extern int zero_clean;
extern int goto_widget_flag;
extern int bar_flag;
extern lv_obj_t * ui_MENU;
extern lv_obj_t * ui_TOUCH;
extern lv_obj_t * ui_JIAOZHUN;
extern lv_obj_t * ui_Label2;
static lv_obj_t * ui_Label;//TOUCH界面label
static lv_obj_t * ui_Label3;//TOUCH界面label3
static lv_obj_t * ui_Labe2;//Menu界面进度条label
static lv_obj_t * bar;//Menu界面进度条
static int val = 100;
/*To use the built-in examples and demos of LVGL uncomment the includes below respectively.
  You also need to copy `lvgl/examples` to `lvgl/src/examples`. Similarly for the demos `lvgl/demos` to `lvgl/src/demos`.
  Note that the `lv_examples` library is for LVGL v7 and you shouldn't install it for this version (since LVGL v8)
  as the examples and demos are now part of the main LVGL library. */
const int _MISO = 12;  // AKA SPI RX
const int _MOSI = 11;  // AKA SPI TX
const int _CS = 22;
const int _SCK = 10;

// include the SD library:
#include <SPI.h>
#include <SD.h>

File root;

#include <Wire.h>
#include "DHT20.h"

DHT20 DHT(&Wire);
DHT20 dht(&Wire1);
#define I2C0_SDA 20
#define I2C0_SCL 21
#define I2C1_0_SDA 2
#define I2C1_0_SCL 3
#define I2C1_1_SDA 6
#define I2C1_1_SCL 7
//串口TX，RX
#define  Serial1_RX 1
#define  Serial1_TX 0
#define  Serial2_RX 5
#define  Serial2_TX 4

//tft背光引脚
#define  LCD_BL 18
#define  IO_LED 19
#define  Uart_LED 25

//无源蜂鸣器
#define Buzzwr_Pin 14
//频率
long frequency = 2700;

//ADC
#define ADC0 26
#define ADC1 27
#define ADC2 28
uint8_t Count = 0;
char CloseData;
char CloseData1;
int NO_Test_Flag = 0;
int Test_Flag = 0;
int Close_Flag = 0;

int touch_flag = 0;
unsigned char buffer[256]; // buffer array for data recieve over serial port
int count = 0;   // counter for buffer array
void clearBufferArray()              // function to clear buffer array
{
  for (int i = 0; i < count; i++)
  {
    buffer[i] = NULL; // clear all index of array with command NULL
  }
}
/*Change to your screen resolution*/
static const uint16_t screenWidth  = 480;
static const uint16_t screenHeight = 320;

static lv_disp_draw_buf_t draw_buf;
static lv_color_t buf1[ screenWidth * screenHeight / 8 ];
//static lv_color_t buf2[ screenWidth * screenHeight / 8 ];
TFT_eSPI tft = TFT_eSPI(); /* TFT instance screenWidth, screenHeight */

#if LV_USE_LOG != 0
/* Serial1 debugging */
void my_print(const char * buf)
{
  Serial1.printf(buf);
  Serial1.flush();
}
#endif

/* Display flushing */
void my_disp_flush( lv_disp_drv_t *disp_drv, const lv_area_t *area, lv_color_t *color_p )
{
  uint32_t w = ( area->x2 - area->x1 + 1 );
  uint32_t h = ( area->y2 - area->y1 + 1 );

  tft.startWrite();
  tft.setAddrWindow( area->x1, area->y1, w, h );
  tft.pushColors( ( uint16_t * )&color_p->full, w * h, true );
  tft.endWrite();

  lv_disp_flush_ready( disp_drv );
}

uint16_t touchX, touchY;
/*Read Touchpad*/
void my_touchpad_read( lv_indev_drv_t * indev_driver, lv_indev_data_t * data )
{
//  data->state = LV_INDEV_STATE_REL;
  bool touched = tft.getTouch( &touchX, &touchY, 600);
  if ( !touched )
  {
    data->state = LV_INDEV_STATE_REL;
  }
  else
  {
    data->state = LV_INDEV_STATE_PR;

    /*Setting the coordinates*/
    data->point.x = touchX;
    data->point.y = touchY;

    Serial1.print( "Data x " );
    Serial1.println( touchX );

    Serial1.print( "Data y " );
    Serial1.println(  touchY);

    
    Serial.print( "Data x " );
    Serial.println( touchX );

    Serial.print( "Data y " );
    Serial.println(  touchY);
  }
}
uint16_t calData[5] =  { 192, 3590, 335, 3362, 1 };
void callback1()  //Callback function
{
  if (bar_flag == 6)
  {
    if (val > 1)
    {
      val--;
      lv_bar_set_value(bar, val, LV_ANIM_OFF);
      lv_label_set_text_fmt(ui_Labe2, "%d %%", val);
      if(val==0)
        val=100;
    }
    else
    {
      lv_obj_clear_flag(ui_touch, LV_OBJ_FLAG_CLICKABLE);
      lv_label_set_text(ui_Labe2, "Loading");
      delay(150);
      val = 100;
      bar_flag = 0; //停止进度条标志
      goto_widget_flag = 1; //进入widget标志

    }
  }
}
Ticker ticker1(callback1, 30, 0, MILLIS);
void setup()
{

  Serial1.setRX(Serial1_RX);
  Serial1.setTX(Serial1_TX);
  Serial1.begin( 115200 ); /* prepare for possible serial debug */
  Serial2.setRX(Serial2_RX);
  Serial2.setTX(Serial2_TX);
  Serial2.begin( 115200 );
  Serial.begin( 115200 );
  String LVGL_Arduino = "Hello Arduino! ";
  LVGL_Arduino += String('V') + lv_version_major() + "." + lv_version_minor() + "." + lv_version_patch();

  Serial1.println( LVGL_Arduino );
  Serial1.println( "I am LVGL_Arduino" );
  

  
  tft.begin();          /* TFT init */
  tft.setRotation( 1); /* Landscape orientation, flipped */
  tft.invertDisplay(false);
  /*Set the touchscreen calibration data,
    the actual data for your display can be acquired using
    the Generic -> Touch_calibrate example from the TFT_eSPI library*/
  tft.setTouch(calData);
//  touch_calibrate();
  lv_init();
//  delay(1000);

#if LV_USE_LOG != 0
  lv_log_register_print_cb( my_print ); /* register print function for debugging */
#endif

  lv_disp_draw_buf_init( &draw_buf, buf1, NULL, screenWidth * screenHeight / 8 );

  /*Initialize the display*/
  static lv_disp_drv_t disp_drv;
  lv_disp_drv_init( &disp_drv );
  /*Change the following line to your display resolution*/
  disp_drv.hor_res = screenWidth;
  disp_drv.ver_res = screenHeight;
  disp_drv.flush_cb = my_disp_flush;
  disp_drv.draw_buf = &draw_buf;
  lv_disp_drv_register( &disp_drv );

  /*Initialize the (dummy) input device driver*/
      static lv_indev_drv_t indev_drv;
      lv_indev_drv_init( &indev_drv );
      indev_drv.type = LV_INDEV_TYPE_POINTER;
      indev_drv.read_cb = my_touchpad_read;
      lv_indev_drv_register( &indev_drv );

  /* Create simple label */
//  lv_obj_t *label = lv_label_create( lv_scr_act() );
//  lv_label_set_text( label, "Hello Ardino and LVGL!");
//  lv_obj_align( label, LV_ALIGN_CENTER, 0, 0 );

  /* Try an example. See all the examples
     online: https://docs.lvgl.io/master/examples.html
     source codes: https://github.com/lvgl/lvgl/tree/e7f88efa5853128bf871dde335c0ca8da9eb7731/examples */
  //lv_example_btn_1();
  
  tft.fillScreen(TFT_BLACK);
  delay(300);
  pinMode(Uart_LED,OUTPUT);
  digitalWrite(Uart_LED, HIGH);
  pinMode(LCD_BL,OUTPUT);
  digitalWrite(LCD_BL, HIGH);
//  analogWrite(LCD_BL,255);
  

   ui_init();//开机UI界面

   while(1)
  {
        if (goto_widget_flag == 1)//进入widget
    {
      if (ticker1.state() == RUNNING)
      {
        ticker1.stop();
      }
      goto_widget_flag = 0;
      delay(300);
      break;
    }
        if (goto_widget_flag == 3)//进入触摸界面，先把进度条线程关闭
    {
      bar_flag = 0; //停止进度条标志
      if (ticker1.state() == RUNNING)
      {
        ticker1.stop();
      }
      if (first_flag == 0 || first_flag == 1)
      {
        label_xy();
        first_flag = 2;
      }
      if (zero_clean == 1)
      {
        touchX = 0;
        touchY = 0;
        zero_clean = 0;
      }
      lv_label_set_text(ui_Label, "Touch Adjust:");
      lv_label_set_text_fmt(ui_Label3, "%d  %d", touchX, touchY); //显示触摸信息
    }
    if (goto_widget_flag == 4)//触摸界面返回到Menu界面,使进度条加满
    {
      val = 100;
      delay(100);
      ticker1.resume();//每35ms调用callback1
      goto_widget_flag = 0;
    }
    if (goto_widget_flag == 5) //触发校准信号
    {
      lv_scr_load_anim(ui_touch_calibrate, LV_SCR_LOAD_ANIM_NONE, 0, 0, false);
      lv_timer_handler();
      lv_timer_handler();
      delay(100);
      touch_calibrate();//触摸校准
      tft.setTouch( calData );
      lv_scr_load_anim(ui_TOUCH, LV_SCR_LOAD_ANIM_NONE, 0, 0, false);
      lv_timer_handler();
      delay(100);
      goto_widget_flag = 3; //进入触摸界面标志
      touchX = 0;
      touchY = 0;
    }
    if (bar_flag == 6)//刚开机进入Menu界面时运行进度条一次，之后就不再运行
    {
      if (first_flag == 0)
      {
        lv_example_bar();
        ticker1.start();//每35ms调用callback1
        first_flag = 1;
      }
    }
    ticker1.update();
    lv_timer_handler();
  }   
  tft.fillScreen(TFT_BLACK);
  /*Or try out a demo. Don't forget to enable the demos in lv_conf.h. E.g. LV_USE_DEMOS_WIDGETS*/
  lv_demo_widgets();
  // lv_demo_benchmark();
  // lv_demo_keypad_encoder();
  // lv_demo_music();
  // lv_demo_printer();
  // lv_demo_stress();
  


  Serial.println( "Setup done" );
}

void loop()
{
   //延迟打开背光
//  digitalWrite(18, HIGH);



  
  while (NO_Test_Flag == 0)
  {
    lv_timer_handler();
    delay(10);
    CloseData1 = Serial.read();
    if (CloseData1 == 'b')  //Exit
    {
      NO_Test_Flag = 1;
      Test_Flag = 1;
      tft.fillScreen(TFT_BLACK);

      Serial.println("Access to the test program");
      break;
    }
  }

  //*********************************Test Program***************************************
  //*********************************Test Program***************************************
  //*********************************Test Program***************************************
  while (Test_Flag == 1)
  {
    Ce_shi();
  }
  //强制刷新，避免黑屏
  lv_timer_handler();
  lv_obj_invalidate(lv_scr_act()); 



}

void Ce_shi() {
  char serialData;
  if (Serial.available() > 0) {
      serialData = Serial.read();
  }

  switch (serialData) {
    case 'R':
      Close_Flag = 1;
      //      WiFi.disconnect();//Disconnect
      tft.fillScreen(TFT_BLACK);
      Serial1.println("Red Screen");
      Serial.println("Red Screen");
      while (Close_Flag == 1)
      {
        tft.fillScreen(TFT_RED);
        CloseData = Serial1.read();
        CloseData1 = Serial.read();
        if (CloseData == 'I'||CloseData1 == 'I')  //Exit
        {
          Close_Flag = 0;
          tft.fillScreen(TFT_BLACK);
          Serial1.println("Exit Red Screen");
          Serial.println("Exit Red Screen");
          break;
        }
      }
      break;

    case 'G':
      Close_Flag = 1;
      tft.fillScreen(TFT_BLACK);
      Serial1.println("Green Screen");
      Serial.println("Green Screen");
      while (Close_Flag == 1)
      {
        tft.fillScreen(TFT_GREEN);
        CloseData = Serial1.read();
        CloseData1 = Serial.read();
        if (CloseData == 'I'||CloseData1 == 'I')  //Exit
        {
          Close_Flag = 0;
          tft.fillScreen(TFT_BLACK);
          Serial1.println("Exit Green Screen");
          Serial.println("Exit Green Screen");
          break;
        }
      }
      break;

    case 'B':
      Close_Flag = 1;
      tft.fillScreen(TFT_BLACK);
      Serial1.println("Blue Screen");
      Serial.println("Blue Screen");
      while (Close_Flag == 1)
      {
        tft.fillScreen(TFT_BLUE);
        CloseData = Serial1.read();
        CloseData1 = Serial.read();
        if (CloseData == 'I'||CloseData1 == 'I')  //Exit
        {
          Close_Flag = 0;
          tft.fillScreen(TFT_BLACK);
          Serial1.println("Exit blue Screen");
          Serial.println("Exit blue Screen");
          break;
        }
      }
      break;
    case 'w':
      Close_Flag = 1;
      tft.fillScreen(TFT_BLACK);
      Serial1.println("White Screen");
      Serial.println("White Screen");
      while (Close_Flag == 1)
      {
        tft.fillScreen(TFT_WHITE);
        CloseData = Serial1.read();
        CloseData1 = Serial.read();
        if (CloseData == 'I'||CloseData1 == 'I')  //Exit
        {
          Close_Flag = 0;
          tft.fillScreen(TFT_BLACK);
          Serial1.println("Exit White Screen");
          Serial.println("Exit White Screen");
          break;
        }
      }
      break;

    case 'h':
      Close_Flag = 1;
      tft.fillScreen(TFT_BLACK);
      Serial1.println("Gray Screen");
      Serial.println("Gray Screen");
      while (Close_Flag == 1)
      {
        tft.fillScreen(TFT_LIGHTGREY);
        CloseData = Serial1.read();
        CloseData1 = Serial.read();
        if (CloseData == 'I'||CloseData1 == 'I')  //Exit
        {
          Close_Flag = 0;
          tft.fillScreen(TFT_BLACK);
          Serial1.println("Exit Gray Screen");
          Serial.println("Exit Gray Screen");
          break;
        }
      }
      break;
    case 'S':
      Close_Flag = 1;
      tft.fillScreen(TFT_BLACK);
      Serial.println("TF card init");
      SD_test();
      while (Close_Flag == 1)
      {
        CloseData1 = Serial.read();
        if (CloseData1 == 'I')  //Exit
        {
          Close_Flag = 0;
          tft.fillScreen(TFT_BLACK);
          Serial.println("exit TF card init");
          watchdog_reboot(0, 0, 0);
          break;
        }
      }
      break;

    case 'T':
      Close_Flag = 1;
      tft.fillScreen(TFT_BLACK);
      Serial1.println("Touch Screen");
      Serial.println("Touch Screen");
      delay(100);
      touch_flag = 0;
      tft.setCursor(70, 70, 4);
      tft.printf("Please Touch");
      Serial1.println("TOUCH");
      Serial.println("TOUCH");
      delay(100);
      while (Close_Flag == 1)
      {
        uint16_t x, y;
        if (touch_flag < 3)
        {
          if (tft.getTouch(&x, &y))
          {
            if (x > 0 && x < 60 && y > 0 && y < 60 && touch_flag == 0)
            {
              tft.setCursor(140, 120, 4);
              tft.printf("               ");
              tft.setCursor(140, 140, 4);
              tft.printf("               ");
              tft.setCursor(120, 120, 4);
              tft.printf("x: %i     ", x);
              tft.setCursor(120, 140, 4);
              tft.printf("y: %i    ", y);
              Serial1.print( "Data x " );
              Serial1.println( x );
              Serial1.print( "Data y " );
              Serial1.println( y );
              
              Serial.print( "Data x " );
              Serial.println( x );
              Serial.print( "Data y " );
              Serial.println( y );
              touch_flag = 1;
            }
            if (x > 275 && x < 320 && y > 185 && y < 240 && touch_flag == 1)
            {
              tft.setCursor(140, 120, 4);
              tft.printf("               ");
              tft.setCursor(140, 140, 4);
              tft.printf("               ");
              tft.setCursor(120, 120, 4);
              tft.printf("x: %i     ", x);
              tft.setCursor(120, 140, 4);
              tft.printf("y: %i    ", y);
              Serial1.print( "Data x " );
              Serial1.println( x );
              Serial1.print( "Data y " );
              Serial1.println( y );

              Serial.print( "Data x " );
              Serial.println( x );
              Serial.print( "Data y " );
              Serial.println( y );
              touch_flag = 3;
              Serial1.println("OVER");
              Serial.println("OVER");
              delay(100);
              Serial1.println("OVER");
              Serial.println("OVER");
            }
            if (x > 0 && x < 4000 && y > 0 && y < 4000)
            {
              tft.setCursor(140, 120, 4);
              tft.printf("               ");
              tft.setCursor(140, 140, 4);
              tft.printf("               ");
              tft.setCursor(120, 120, 4);
              tft.printf("x: %i     ", x);
              tft.setCursor(120, 140, 4);
              tft.printf("y: %i    ", y);
              Serial1.print( "Data x " );
              Serial1.println( x );
              Serial1.print( "Data y " );
              Serial1.println( y );

              Serial.print( "Data x " );
              Serial.println( x );
              Serial.print( "Data y " );
              Serial.println( y );
            }
            CloseData = Serial1.read();
            CloseData1 = Serial.read();
            if (CloseData == 'I'||CloseData1 == 'I')  //Exit
            {
              Close_Flag = 0;
              touch_flag = 0;
              tft.fillScreen(TFT_BLACK);
              break;
            }
            delay(80);
          }
        }
        if (touch_flag == 3)
        {
          Serial1.println("OVER");
          Serial.println("OVER");
          if (tft.getTouch(&x, &y))
          {
            tft.fillScreen(TFT_BLACK);
            if (x > 0 && x < 4000 && y > 0 && y < 4000)
            {
              tft.setCursor(140, 120, 4);
              tft.printf("               ");
              tft.setCursor(140, 140, 4);
              tft.printf("               ");
              tft.setCursor(120, 120, 4);
              tft.printf("x: %i     ", x);
              tft.setCursor(120, 140, 4);
              tft.printf("y: %i    ", y);
              Serial1.print( "Data x " );
              Serial1.println( x );
              Serial1.print( "Data y " );
              Serial1.println( y );

              Serial.print( "Data x " );
              Serial.println( x );
              Serial.print( "Data y " );
              Serial.println( y );
            }
          }
          delay(80);
        }
        CloseData = Serial1.read();
        CloseData1 = Serial.read();
        if (CloseData == 'I'||CloseData1 == 'I')  //Exit
        {
          Close_Flag = 0;
          tft.fillScreen(TFT_BLACK);
          Serial1.println("Exit Touch Screen");
          Serial.println("Exit Touch Screen");
          break;
        }

      }
      break;

    case 'L':
      Close_Flag = 1;
      Serial.println("IO Port Test");
      tft.fillScreen(TFT_BLACK);
      tft.setCursor(50, 100, 4);
      tft.printf("IO port output testing");
      pinMode(IO_LED,OUTPUT);
      while (Close_Flag == 1)
      {
        digitalWrite(IO_LED, HIGH);//Pull high level to turn on the light
 
        CloseData1 = Serial.read();
        if (CloseData1 == 'I')  //Exit
        {
          Close_Flag = 0;
          digitalWrite(IO_LED, LOW);
          tft.fillScreen(TFT_BLACK);
 
          Serial.println("Exit IO port test");
          break;
        }
      }
      break;

    case 'i':
      Close_Flag = 1;
      Wire.setSDA(I2C0_SDA);
      Wire.setSCL(I2C0_SCL);
      Wire.begin();
      DHT.begin();    //  ESP32 default pins 21 22
 
      Serial1.println("IIC");
      Serial.println("IIC");
      tft.fillScreen(TFT_BLACK);
      tft.setCursor(100, 100, 4);
      tft.printf("IIC testing");
      while (Close_Flag == 1)
      {
          if(millis() - DHT.lastRead() >= 1000)
          {
            //  READ DATA
            uint32_t start = micros();
            int status = DHT.read();
            uint32_t stop = micros();
        
            if ((Count % 10) == 0)
            {
              Count = 0;
              Serial1.println();
              Serial1.println("Type\tHumidity (%)\tTemp (°C)\tTime (µs)\tStatus");
              Serial.println();
              Serial.println("Type\tHumidity (%)\tTemp (°C)\tTime (µs)\tStatus");
            }
            Count++;
        
            Serial1.print("DHT20 \t");
            //  DISPLAY DATA, sensor has only one decimal.
            Serial1.print(DHT.getHumidity(), 1);
            Serial1.print("\t\t");
            Serial1.print(DHT.getTemperature(), 1);
            Serial1.print("\t\t");
            Serial1.print(stop - start);
            Serial1.print("\t\t");

            Serial.print("DHT20 \t");
            //  DISPLAY DATA, sensor has only one decimal.
            Serial.print(DHT.getHumidity(), 1);
            Serial.print("\t\t");
            Serial.print(DHT.getTemperature(), 1);
            Serial.print("\t\t");
            Serial.print(stop - start);
            Serial.print("\t\t");
            switch (status)
            {
              case DHT20_OK:
                Serial1.print("OK");
                Serial.print("OK");
                break;
              case DHT20_ERROR_CHECKSUM:
                Serial1.print("Checksum error");
                Serial.print("Checksum error");
                break;
              case DHT20_ERROR_CONNECT:
                Serial1.print("Connect error");
                Serial.print("Connect error");
                break;
              case DHT20_MISSING_BYTES:
                Serial1.print("Missing bytes");
                Serial.print("Missing bytes");
                break;
              case DHT20_ERROR_BYTES_ALL_ZERO:
                Serial1.print("All bytes read zero");
                Serial.print("All bytes read zero");
                break;
              case DHT20_ERROR_READ_TIMEOUT:
                Serial1.print("Read time out");
                Serial.print("Read time out");
                break;
              case DHT20_ERROR_LASTREAD:
                Serial1.print("Error read too fast");
                Serial.print("Error read too fast");
                break;
              default:
                Serial1.print("Unknown error");
                Serial.print("Unknown error");
                break;
            }
            Serial1.print("\n");
            Serial.print("\n");
          }
 
        CloseData = Serial1.read();
        CloseData1 = Serial.read();
        if (CloseData == 'I'||CloseData1 == 'I')  //Exit
        {
          Close_Flag = 0;
          tft.fillScreen(TFT_BLACK);
          Serial1.println("Exit IIC");
          Serial.println("Exit IIC");
          break;
        }
      }
      break;
    case 'j':
        Close_Flag = 1;
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

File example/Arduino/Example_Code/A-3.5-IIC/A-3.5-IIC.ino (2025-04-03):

#include <Arduino.h>

//#include <TFT_eSPI.h>

#include <Wire.h>
#include "DHT20.h"



DHT20 DHT(&Wire);

#define I2C0_SDA 20
#define I2C0_SCL 21


void setup()
{
 
  Serial.begin( 115200 );

  Wire.setSDA(I2C0_SDA);
  Wire.setSCL(I2C0_SCL);
  Wire.begin();
  DHT.begin(); 

  

 

  

  delay(100);

}

void loop()
{

  char DHT_buffer[6];

  int status = DHT.read();
  
  int a = (int)DHT.getTemperature();
  int b = (int)DHT.getHumidity();
  Serial.print("Temperature:");
  Serial.println(a);
  Serial.print("getHumidity:");
  Serial.println(b);

  delay( 500 );

}
